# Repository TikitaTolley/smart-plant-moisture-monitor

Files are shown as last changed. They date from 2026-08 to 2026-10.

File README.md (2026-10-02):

# Smart Plant Moisture Monitor

> An ESP32 smart plant monitor with a capacitive soil sensor, a 3D-printed RGB status lamp and an installable pixel-art PWA.

The finished build uses soldered electronics inside a 3D-printed controller enclosure. After a short overheated the original board, I rebuilt the circuit on a new board, tested it and fitted it into the case.

[][yt]
[][tt]
[][ig]

<p>
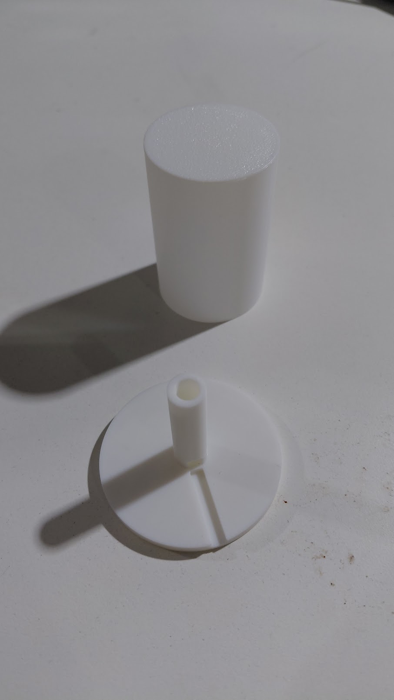
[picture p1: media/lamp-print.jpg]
Printed lamp shade and base
  
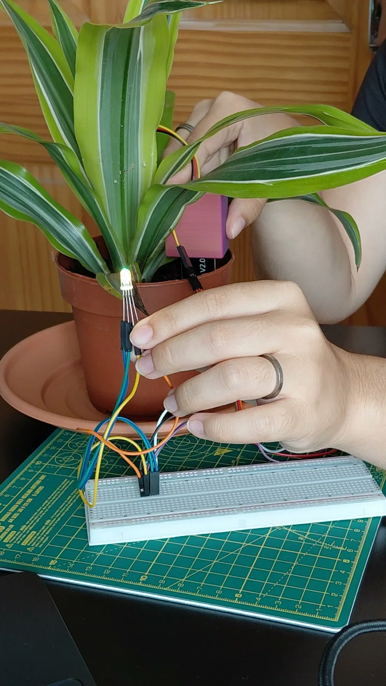
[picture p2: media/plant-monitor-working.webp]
Working ESP32 plant monitor with a soil sensor and green status LED beside the plant
  
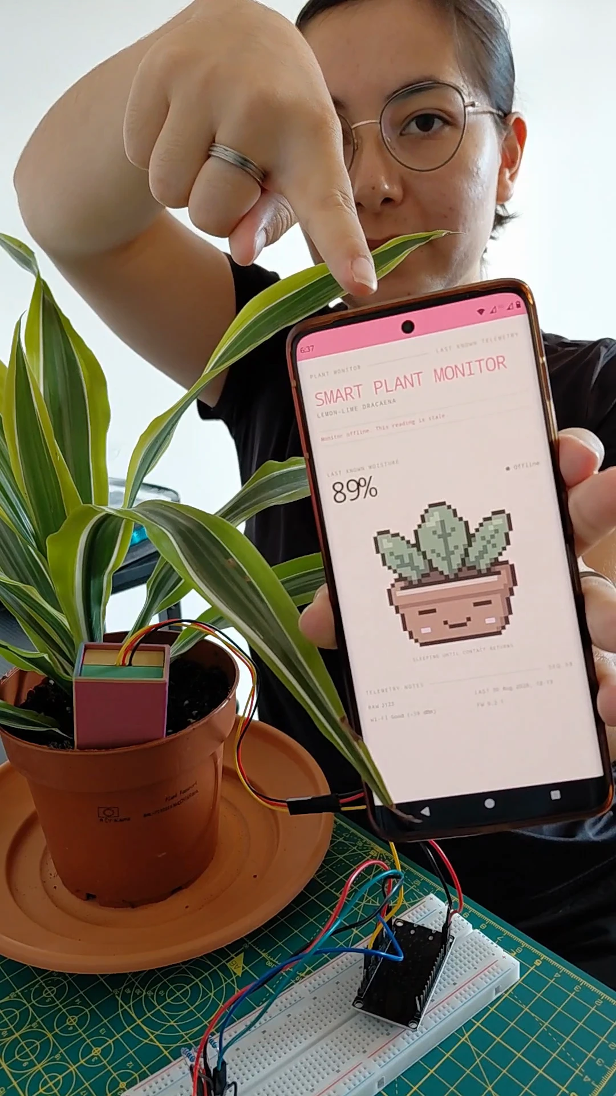
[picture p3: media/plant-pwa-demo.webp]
Tikita holding the Smart Plant Monitor PWA beside the plant, soil sensor, and ESP32 circuit
  
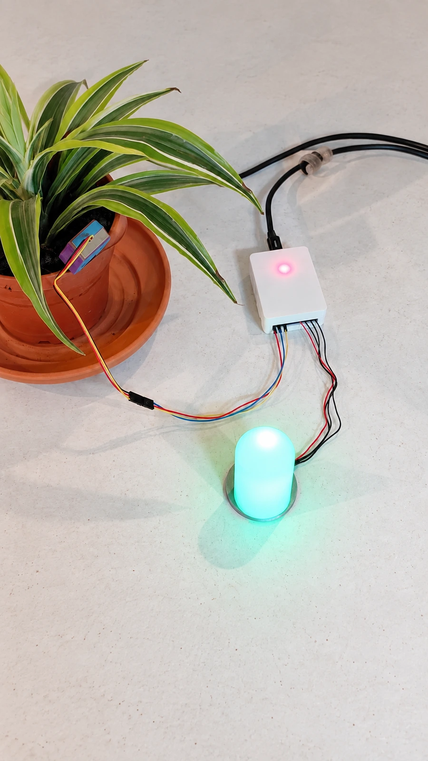
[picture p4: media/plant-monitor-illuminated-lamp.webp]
Finished Smart Plant Moisture Monitor with the plant sensor, controller enclosure and illuminated RGB status lamp
  
</p>

**[Open the live Smart Plant Monitor][live-pwa]**

## What it does

A capacitive sensor reads the soil moisture around the plant. The ESP32 shows the current status on the RGB lamp and sends the reading to a Cloudflare-backed PWA.

The monitor has three live moisture states:

| Moisture state | Lamp | PWA character |
| --- | --- | --- |
| Moist | Green | Happy |
| Getting dry | Yellow | Worried |
| Dry | Red | Sad |

The sleeping character means the monitor is offline.

## Simulated circuit

| Simulator | Link | Notes |
| --- | --- | --- |
| Wokwi | [Open the simulation][wokwi] | ESP32, moisture input, and RGB output logic |

## Bill of materials

| Qty | Component | Part | Unit cost | Notes |
| --- | --- | --- | --- | --- |
| 1 | Starter kit | ESP32 Basic Starter Kit | £12.89 bundle | Shared purchase; included parts below are not charged again |
| 1 | Microcontroller | ESP32 development board | Included in kit | 3.3 V logic |
| 1 | Perfboard | 50 x 70 mm | From £8.99 assorted pack | Soldered circuit |
| 2 | Female header strips | Cut to 15 contacts | £0.10 per strip | ESP32 sockets |
| 3 | Terminal blocks | One 3-way, two 2-way | Pack cost not allocated | Sensor and lamp connections |
| 1 | USB cable | Data cable | Owned | |
| 1 | RGB LED | 5 mm, common cathode | Included in kit | One of two supplied in the kit |
| 3 | Resistor | 220 Ω from assorted pack | Included in kit | Three of 30 supplied in the kit |
| As needed | Wire | Jumpers and hook-up wire | Shared supplies | |
| 1 | Soil moisture sensor | Capacitive v1.2 | £0.48 | 3.3 to 5.5 V input, 0 to 3.0 V output, PH2.0-3P, 98 x 23 mm |
| 38.02 g | Lamp and sensor-case parts | PLA Basic | £1.33 | 26.16 g colourful white + 11.86 g white |
| 60.32 g | Controller-enclosure prints | White PLA | £2.11 | Recorded as 44.14 g + 16.18 g |
| 1 | Mains USB plug | 5 V USB | Owned | |
| 1 | Plant | Potted plant | £4.99 | |

## Wiring

| Component | Pin | ESP32 connection | Notes |
| --- | --- | --- | --- |
| Soil moisture sensor | VCC | 3V3 | Shared 3.3 V rail |
| Soil moisture sensor | GND | GND | Common ground |
| Soil moisture sensor | AOUT | GPIO 34 | ADC1 pin |
| RGB LED | Common cathode | GND | |
| RGB LED | Red anode | GPIO 25 through 220 Ω | PWM |
| RGB LED | Green anode | GPIO 26 through 220 Ω | PWM |
| RGB LED | Blue anode | GPIO 27 through 220 Ω | PWM |

## Firmware

The Arduino sketch is [`main/main.ino`](main/main.ino). It uses the ESP32 Arduino core.

1. Copy `main/secrets.example.h` to `main/secrets.h`.
2. Add the Wi-Fi details, API URL, and device key.
3. Open `main/main.ino` in Arduino IDE.
4. Select the matching ESP32 board and port, then upload the sketch.
5. Open Serial Monitor at 115200 baud.

### Soil calibration

Current references: `dryRaw = 2559`, `wetRaw = 1741`. For your plant, average the Serial Monitor raw readings in dry soil and after watering has settled, then update those two constants. The percentage is relative to your references.

## Web app

The installable React and Vite PWA receives readings through a Cloudflare Worker and stores them in D1.

[Open the live Smart Plant Monitor][live-pwa]

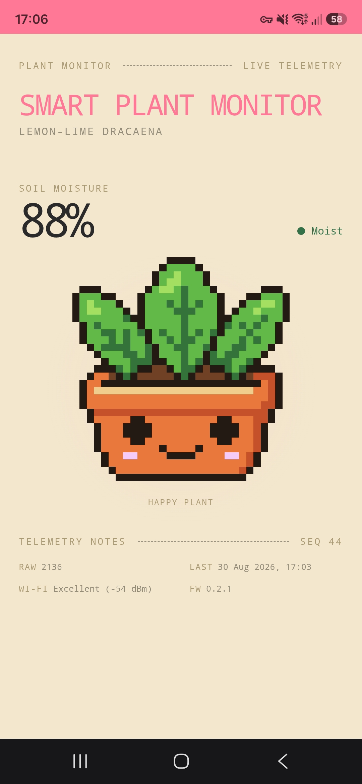
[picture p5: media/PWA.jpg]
Smart Plant Monitor PWA showing a pixel-art plant character


```sh
cd app
bun install
bun run dev
```

See [app setup](app/README.md) for the device key, database and deployment steps.

## Printed sensor case

The sensor case is based on [danielkrah's Capacitive Soil Moisture Sensor v1.2 Case][printables-vendor]. The four parts used here are in `print/stl/`:

| File | Part |
| --- | --- |
| [v4-outer-box.stl](print/stl/v4-outer-box.stl) | Protective sleeve |
| [v4-upper-case.stl](print/stl/v4-upper-case.stl) | Upper case half |
| [v4-bottom-case.stl](print/stl/v4-bottom-case.stl) | Lower case half |
| [v4-sensor-dummy.stl](print/stl/v4-sensor-dummy.stl) | Fit-test sensor dummy |

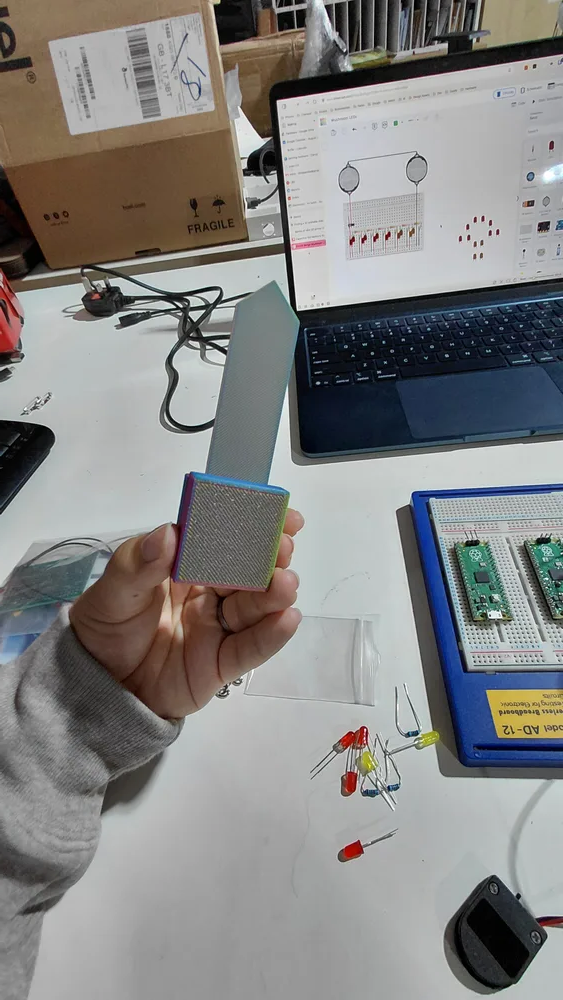
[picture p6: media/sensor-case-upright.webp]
Printed sensor case


## RGB lamp head

The custom shade softens the LED and the base routes the four LED wires into the stake. The tested files target a **Bambu Lab P1S with a 0.4 mm nozzle** and use 0.2 mm layers.

| File | Contents |
| --- | --- |
| [print/3mf/lamp-shade-project.3mf](print/3mf/lamp-shade-project.3mf) | Combined Bambu Studio project with verified shade and v3 base |
| [print/3mf/lamp-shade-final.3mf](print/3mf/lamp-shade-final.3mf) | Verified shade, 0% infill |
| [print/3mf/lamp-shade-base-v3-final.3mf](print/3mf/lamp-shade-base-v3-final.3mf) | Verified base, 15% infill |
| [print/3mf/print-profile.3mf](print/3mf/print-profile.3mf) | Two configured plates: shade at 0% infill and v3 base at 15% infill |

The lamp files are also published as [RGB LED Lamp Shade on MakerWorld][makerworld-lamp].

## Controller enclosure

The USB-powered ESP32 and soldered perfboard sit inside a case with a removable carrier and lid.

| CAD download | Part |
| --- | --- |
| [Body](cad/controller/controller-body.step) | Perfboard supports and wire clearance |
| [Carrier](cad/controller/controller-carrier.step) | Removable ESP32 support |
| [Lid](cad/controller/controller-lid.step) | Lift-off cover |

These STEP files need orientation and slicing for your printer.
The [Onshape source document][onshape-controller] contains the design history and named revisions.
The controller enclosure is available through GitHub rather than model-sharing platforms.

<p>
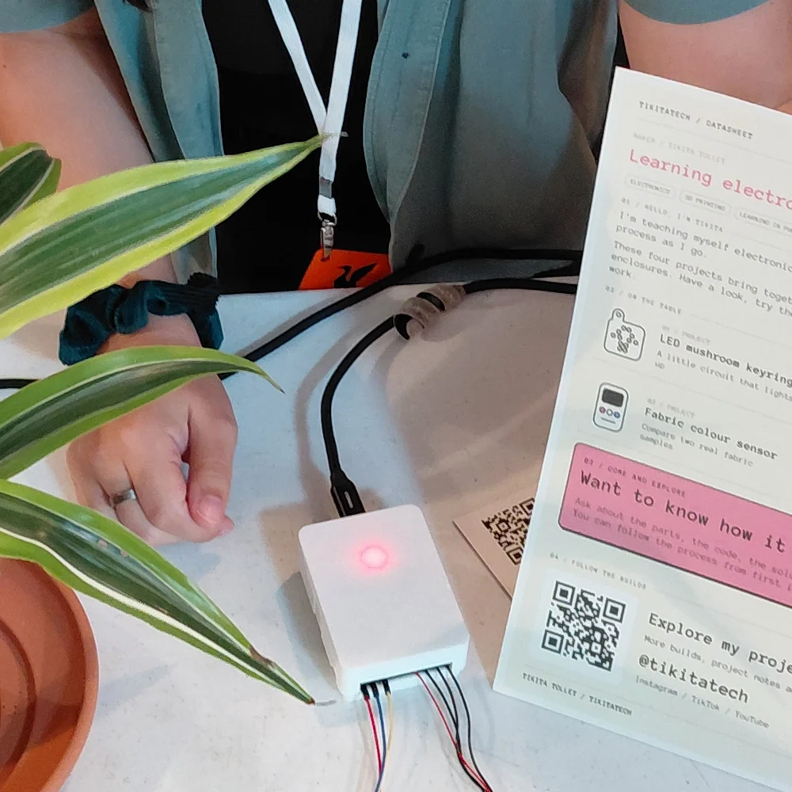
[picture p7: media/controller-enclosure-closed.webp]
Finished Smart Plant Moisture Monitor controller enclosure
  
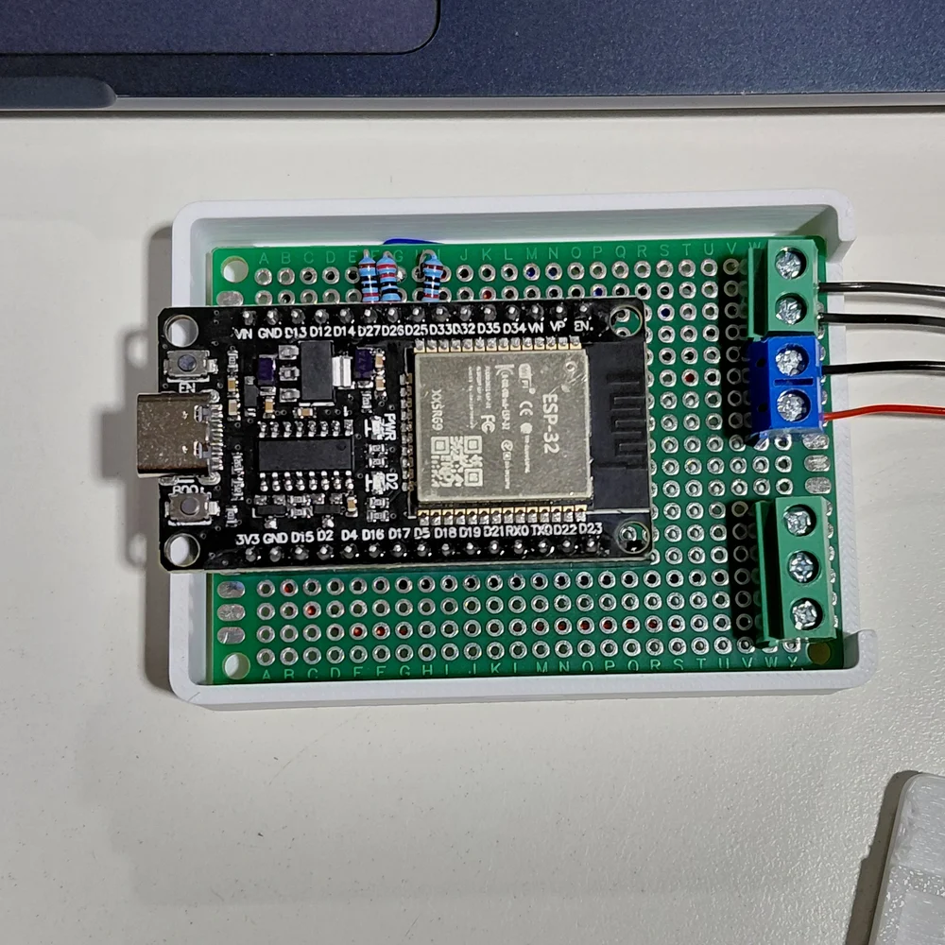
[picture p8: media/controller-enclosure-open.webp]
Open Smart Plant Moisture Monitor controller enclosure showing the ESP32, perfboard and terminal blocks
  
</p>

## Build videos

- [Prototype to finished build](https://www.youtube.com/shorts/TpMN1hflvZs)
- [Board rebuild](https://www.youtube.com/shorts/PaTFUJps23Y)

## This project elsewhere

| Where | Link | What is there |
| --- | --- | --- |
| Live PWA | [Open the Smart Plant Monitor][live-pwa] | Latest reading and pixel-art moisture state |
| Portfolio | [Read the project page][portfolio] | Full build overview |
| MakerWorld | [RGB LED Lamp Shade][makerworld-lamp] | Lamp files and print details |
| Onshape | [Open the controller enclosure source][onshape-controller] | Controller design history and named revisions |
| Printables | [Original sensor case][printables-vendor] | Source enclosure design by danielkrah |
| YouTube Shorts | [Watch Part 1][part1-youtube] · [Watch Part 2][part2-youtube] | RGB lamp build and wireless PWA build |
| TikTok | [Watch Part 1][part1-tiktok] · [Watch Part 2][part2-tiktok] | RGB lamp build and wireless PWA build |
| Instagram | [Watch Part 1][part1-instagram] · [Watch Part 2][part2-instagram] | RGB lamp build and wireless PWA build |

## Licences

- Software and firmware: [MIT](LICENSE)
- Original lamp shade, base, controller CAD, build documentation and released project photographs: [CC BY-NC-SA 4.0](LICENSE)
- Sensor-case meshes by danielkrah: [CC BY-SA 4.0](LICENSE)

---

All projects at [github.com/TikitaTolley][gh].

[yt]: https://youtube.com/@tikitatech
[tt]: https://tiktok.com/@tikitatech
[ig]: https://instagram.com/tikitatech
[gh]: https://github.com/TikitaTolley
[portfolio]: https://tikitatech.xyz/projects/smart-plant-moisture-monitor/
[wokwi]: https://wokwi.com/projects/471268493966479361
[makerworld-lamp]: https://makerworld.com/en/models/3173248-rgb-led-lamp-shade
[onshape-controller]: https://cad.onshape.com/documents/6bfe477083b9e3ae1efd160d/w/e42f85ce378bae2f44ccfe51/e/629ef28bf58cca82b9749cb0
[printables-vendor]: https://www.printables.com/model/277601-capacitive-soil-moisture-sensor-v12-case-waterproo
[part1-youtube]: https://youtube.com/shorts/DsD2whw1M_8
[part1-tiktok]: https://www.tiktok.com/@tikitatech/video/7675019173306633494
[part1-instagram]: https://www.instagram.com/reel/DcJU_JGqnMz/
[part2-youtube]: https://youtube.com/shorts/lq9Cll0Gkk8
[part2-tiktok]: https://www.tiktok.com/@tikitatech/video/7680212442886032673
[part2-instagram]: https://www.instagram.com/reel/DctX8B5qHho/
[live-pwa]: https://smart-plant-monitor.daeda-technologies.workers.dev

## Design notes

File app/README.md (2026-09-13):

# Smart Plant Monitor app

An installable React PWA, Cloudflare Worker and D1 database. [Open the live monitor](https://smart-plant-monitor.daeda-technologies.workers.dev/).

## Local setup

From the repository root, with Bun installed:

```sh
cd app
bun install
cp .dev.vars.example .dev.vars
bunx wrangler d1 migrations apply smart-plant-monitor --local
bun run dev
```

Set `DEVICE_KEY` in `.dev.vars` to your own random secret. In another terminal, from `app/`, run `bun run simulate:local` to send synthetic readings.

## Deploy your own

1. Run `bunx wrangler login`, then `bunx wrangler d1 create smart-plant-monitor` in your Cloudflare account.
2. Set your Worker name and returned database ID in [wrangler.jsonc](wrangler.jsonc). Keep the binding `DB`.
3. Apply the migration, set your device key and deploy:

```sh
bunx wrangler d1 migrations apply smart-plant-monitor --remote
bunx wrangler secret put DEVICE_KEY
bun run deploy
```

In `main/secrets.h`, set the same device key, your Wi-Fi details and `API_URL` to `https://YOUR-WORKER.workers.dev/api/v1/readings/`.

[Cloudflare database setup](https://developers.cloudflare.com/d1/get-started/) · [Worker secrets](https://developers.cloudflare.com/workers/configuration/secrets/)

## Checks

```sh
bun run build
bun run lint
```

The firmware calculates the moisture state; the app displays it. A sleeping character means the device is offline.

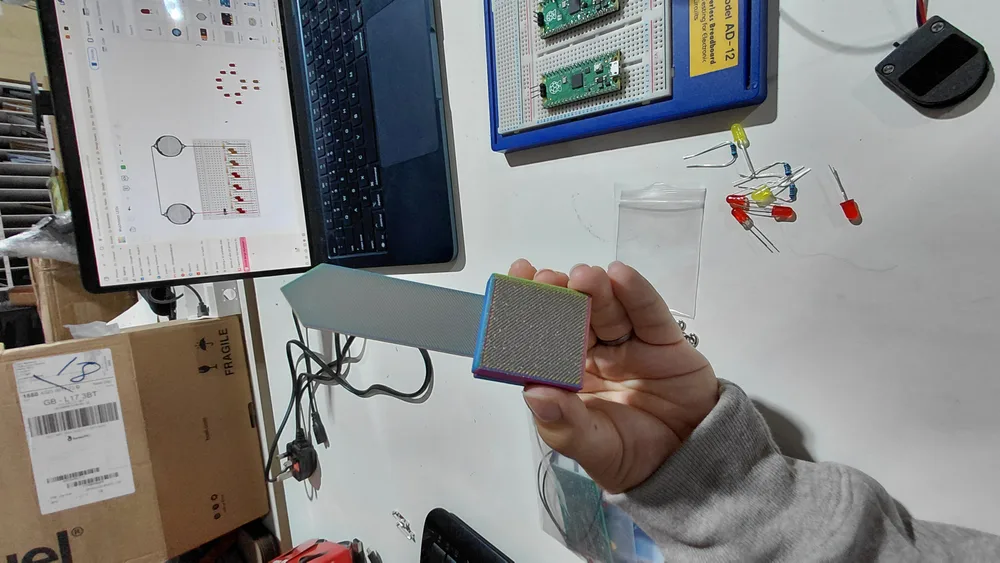
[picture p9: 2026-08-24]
media/sensor-case.webp

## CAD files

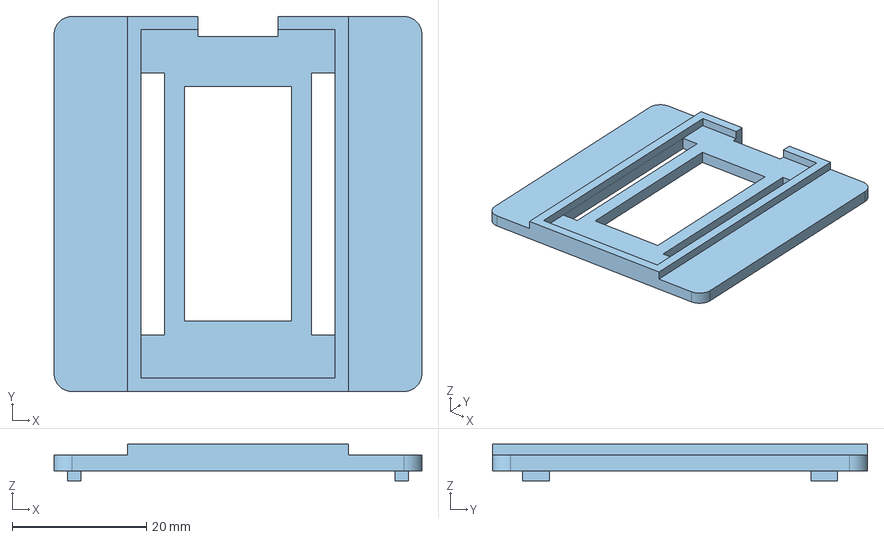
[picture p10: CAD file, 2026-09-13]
cad/controller/controller-carrier.step
54.9 x 56.0 x 5.50 mm

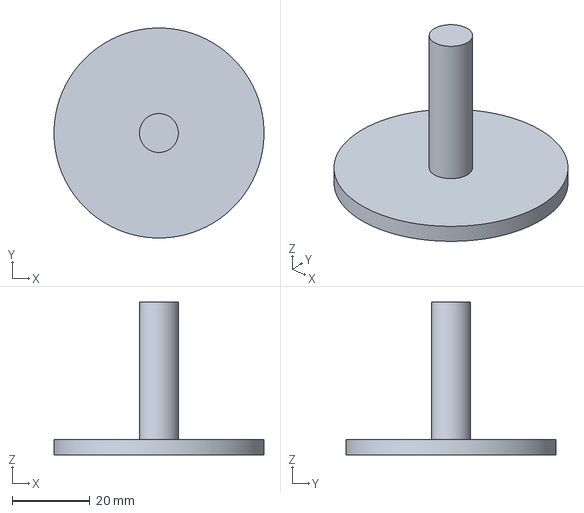
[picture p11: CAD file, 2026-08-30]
print/3mf/early-iterations/lamp-shade-base-v2-final.3mf
54.0 x 54.0 x 39.3 mm

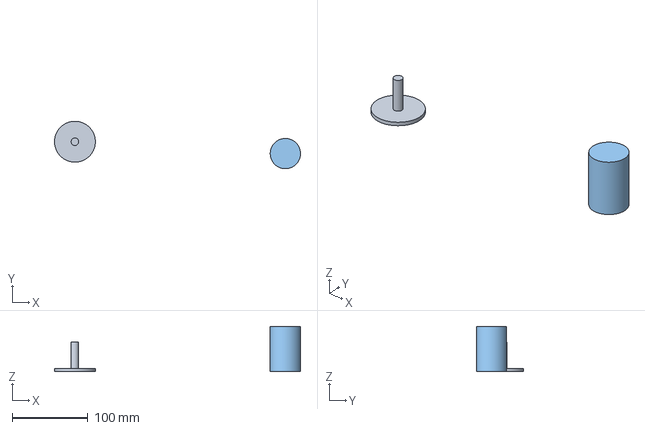
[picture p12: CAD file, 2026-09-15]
print/3mf/print-profile.3mf
324.9 x 62.7 x 60.0 mm

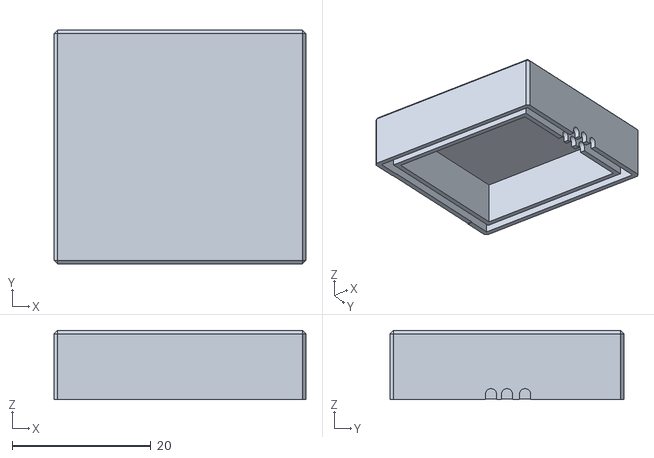
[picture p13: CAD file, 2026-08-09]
print/stl/v4-upper-case.stl
36.3 x 33.7 x 10.0

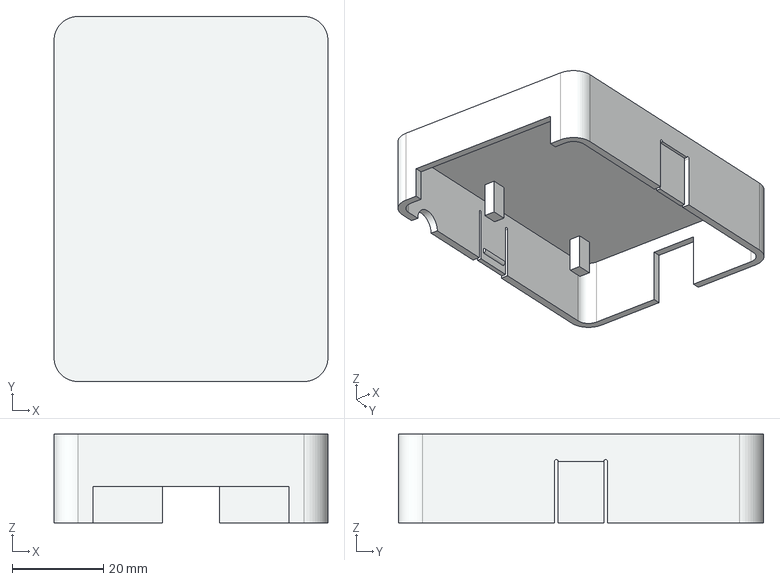
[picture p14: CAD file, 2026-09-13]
cad/controller/controller-lid.step
60.1 x 80.1 x 19.5 mm

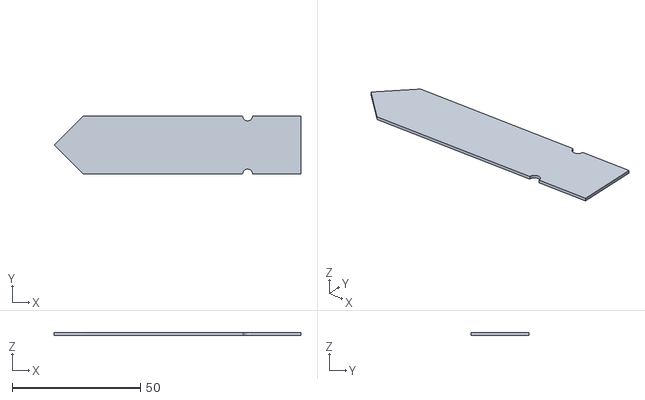
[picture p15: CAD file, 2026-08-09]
print/stl/v4-sensor-dummy.stl
96.2 x 22.6 x 1.00

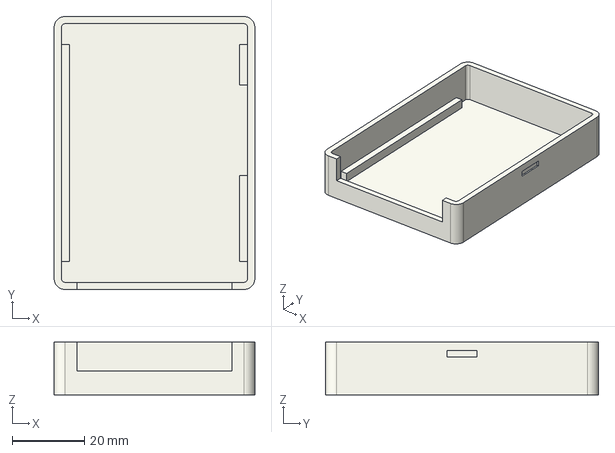
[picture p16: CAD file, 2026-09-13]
cad/controller/controller-body.step
55.5 x 75.5 x 14.6 mm

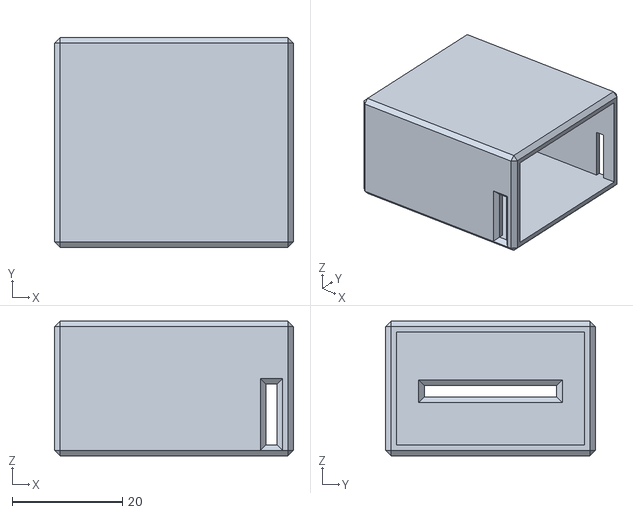
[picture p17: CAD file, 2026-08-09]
print/stl/v4-outer-box.stl
43.3 x 38.1 x 24.4

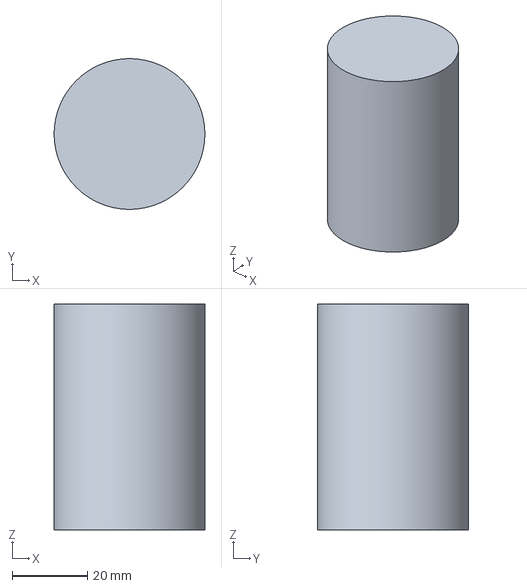
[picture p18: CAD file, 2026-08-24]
print/3mf/lamp-shade-final.3mf
40.0 x 40.0 x 60.0 mm

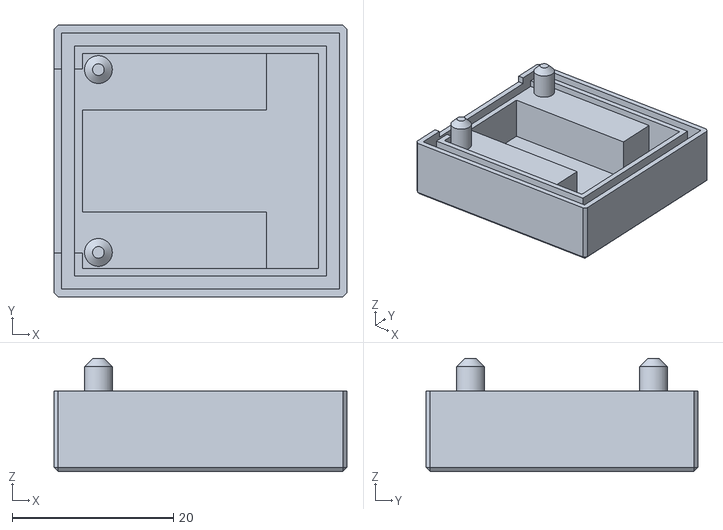
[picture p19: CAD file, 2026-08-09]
print/stl/v4-bottom-case.stl
36.3 x 33.7 x 14.0

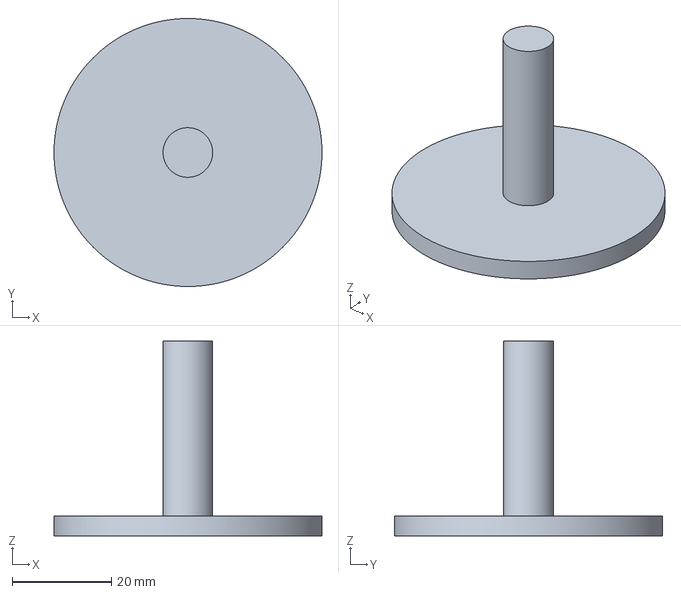
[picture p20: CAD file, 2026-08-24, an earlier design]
print/3mf/early-iterations/lamp-shade-base-final.3mf
54.0 x 54.0 x 39.3 mm

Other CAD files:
print/3mf/lamp-shade-project.3mf
print/3mf/lamp-shade-base-v3-final.3mf

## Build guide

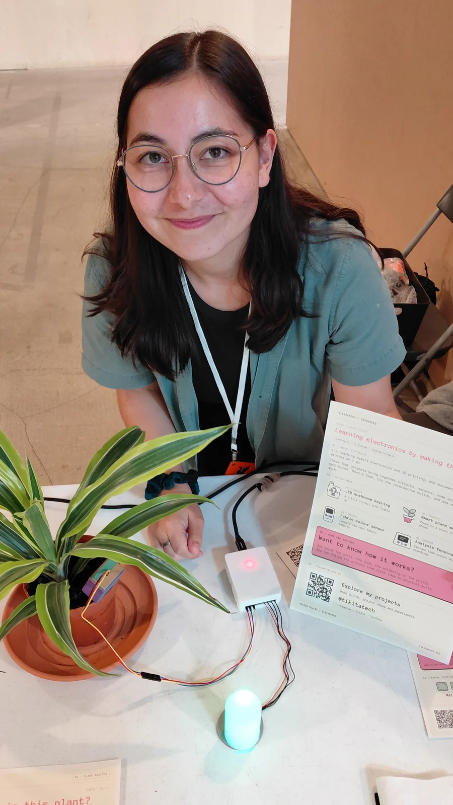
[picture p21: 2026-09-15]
media/plant-monitor-makefest.webp

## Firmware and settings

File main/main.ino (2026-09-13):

#include <HTTPClient.h>
#include <NetworkClientSecure.h>
#include <Preferences.h>
#include <WiFi.h>
#include <time.h>
#include "certificates.h"
#include "secrets.h"

constexpr int moisturePin = 34;
constexpr int redPin = 25;
constexpr int greenPin = 26;
constexpr int bluePin = 27;

constexpr int dryRaw = 2559; // measured dry-soil reference
constexpr int wetRaw = 1741; // settled after light watering; relative reference
constexpr char deviceId[] = "lemon-lime-dracaena-01";
constexpr char firmwareVersion[] = "0.3.0";
constexpr unsigned long uploadIntervalMs = 300000;
constexpr time_t minimumValidTime = 1700000000;

unsigned long sequence = 1;
unsigned long lastUploadAttemptAt = 0;
unsigned long lastSerialReadingAt = 0;
bool firstUploadAttempted = false;
Preferences preferences;
bool preferencesReady = false;
char pendingPayload[256];
bool hasPendingReading = false;

void loadSequence() {
  preferencesReady = preferences.begin("plant-monitor", false);

  if (!preferencesReady) {
    Serial.println("Failed to open sequence storage");
    return;
  }

  sequence = preferences.getULong("next-seq", 1);
  Serial.print("Next reading sequence: ");
  Serial.println(sequence);
}

bool advanceSequence() {
  if (!preferencesReady) {
    Serial.println("Sequence storage is unavailable");
    return false;
  }

  if (sequence == UINT32_MAX) {
    Serial.println("Sequence has reached its maximum value");
    return false;
  }

  const unsigned long nextSequence = sequence + 1;

  if (preferences.putULong("next-seq", nextSequence) == 0) {
    Serial.println("Failed to save sequence");
    return false;
  }

  sequence = nextSequence;
  return true;
}

float moisturePercent(int raw) {
  const float percent =
    100.0f * (dryRaw - raw) / (dryRaw - wetRaw);
  return constrain(percent, 0.0f, 100.0f);
}

int readAverageMoisture() {
  constexpr int sampleCount = 10;
  int total = 0;

  for (int sample = 0; sample < sampleCount; sample++) {
    total += analogRead(moisturePin);
    delay(10);
  }

  return total / sampleCount;
}

const char* moistureStatus(int percent) {
  if (percent <= 25) {
    return "dry";
  }

  if (percent <= 45) {
    return "getting-dry";
  }

  return "moist";
}

bool formatReadingJson(
  char* buffer,
  size_t bufferSize,
  int raw,
  int percent
) {
  const char* status = moistureStatus(percent);
  const int rssi = WiFi.RSSI();

  const int length = snprintf(
    buffer,
    bufferSize,
    "{\"deviceId\":\"%s\","
    "\"sequence\":%lu,"
    "\"raw\":%d,"
    "\"moisturePercent\":%d,"
    "\"status\":\"%s\","
    "\"rssi\":%d,"
    "\"firmwareVersion\":\"%s\"}",
    deviceId,
    sequence,
    raw,
    percent,
    status,
    rssi,
    firmwareVersion
  );

  return length >= 0 && static_cast<size_t>(length) < bufferSize;
}

bool clockIsReady() {
  return time(nullptr) >= minimumValidTime;
}

bool sendReading(const char* payload) {
  if (WiFi.status() != WL_CONNECTED) {
    Serial.println("Upload deferred: Wi-Fi is disconnected");
    return false;
  }

  if (!clockIsReady()) {
    Serial.println("Upload deferred: waiting for clock sync");
    return false;
  }

  NetworkClientSecure client;
  client.setCACert(gtsRootR4);

  HTTPClient http;

  if (!http.begin(client, API_URL)) {
    Serial.println("Failed to start HTTPS request");
    return false;
  }

  const String authorization = String("Bearer ") + DEVICE_KEY;
  http.addHeader("Authorization", authorization);
  http.addHeader("Content-Type", "application/json");

  Serial.print("Uploading sequence ");
  Serial.println(sequence);

  const int responseCode = http.POST(String(payload));
  const bool accepted = responseCode == 200 || responseCode == 201;

  if (responseCode > 0) {
    Serial.print("Worker response: ");
    Serial.println(responseCode);
  } else {
    Serial.print("HTTPS request failed: ");
    Serial.println(http.errorToString(responseCode));
  }

  http.end();
  return accepted;
}

void setColour(int red, int green, int blue) {
  analogWrite(redPin, red);
  analogWrite(greenPin, green);
  analogWrite(bluePin, blue);
}

constexpr unsigned long wifiRetryIntervalMs = 30000;

unsigned long lastWifiAttemptAt = 0;
bool wifiWasConnected = false;

void startWifi() {
  Serial.print("Connecting to ");
  Serial.println(WIFI_SSID);

  WiFi.mode(WIFI_STA);
  WiFi.begin(WIFI_SSID, WIFI_PASSWORD);

  lastWifiAttemptAt = millis();
}

void maintainWifi() {
  const bool wifiIsConnected = WiFi.status() == WL_CONNECTED;

  if (wifiIsConnected) {
    if (!wifiWasConnected) {
      Serial.println("Wi-Fi connected");
      Serial.print("IP address: ");
      Serial.println(WiFi.localIP());
      configTime(0, 0, "pool.ntp.org", "time.nist.gov");
      Serial.println("Clock sync requested");
    }

    wifiWasConnected = true;
    return;
  }

  if (wifiWasConnected) {
    Serial.println("Wi-Fi disconnected");
  }

  wifiWasConnected = false;

  const unsigned long now = millis();

  if (now - lastWifiAttemptAt < wifiRetryIntervalMs) {
    return;
  }

  lastWifiAttemptAt = now;

  Serial.println("Retrying Wi-Fi connection...");
  WiFi.reconnect();
}

void setup() {
  Serial.begin(115200);

  loadSequence();
  analogReadResolution(12);

  pinMode(redPin, OUTPUT);
  pinMode(greenPin, OUTPUT);
  pinMode(bluePin, OUTPUT);

  Serial.println("Smart Plant Moisture Monitor ready");
  startWifi();
}

void loop() {
  maintainWifi();
  const int moisture = readAverageMoisture();

  const int percent = moisturePercent(moisture);

  const unsigned long now = millis();

  if (percent <= 25) {
    setColour(255, 0, 0);     // dry: red
  } else if (percent <= 45) {
    setColour(255, 100, 0);   // getting dry: yellow
  } else {
    setColour(0, 255, 0);     // moist: green
  }

  if (now - lastSerialReadingAt >= 1000) {
    lastSerialReadingAt = now;
    Serial.printf("raw=%d relativeMoisture=%d%% status=%s wifi=%s\n",
      moisture, percent, moistureStatus(percent),
      WiFi.status() == WL_CONNECTED ? "connected" : "disconnected");
  }

  // Allow settling before the first online reading, then retain five-minute uploads.
  const bool firstUploadReady = !firstUploadAttempted && now >= 30000 &&
    WiFi.status() == WL_CONNECTED && clockIsReady();
  const bool nextUploadReady = firstUploadAttempted &&
    now - lastUploadAttemptAt >= uploadIntervalMs;

  if (firstUploadReady || nextUploadReady) {
    firstUploadAttempted = true;
    lastUploadAttemptAt = now;

    if (!hasPendingReading) {
      hasPendingReading = formatReadingJson(
        pendingPayload,
        sizeof(pendingPayload),
        moisture,
        percent
      );

      if (hasPendingReading) {
        Serial.print("Reading queued: ");
        Serial.println(pendingPayload);
      } else {
        Serial.println("Reading JSON was too large");
      }
    }

    if (hasPendingReading && sendReading(pendingPayload)) {
      if (advanceSequence()) {
        hasPendingReading = false;
        pendingPayload[0] = '\0';
        Serial.println("Reading accepted and sequence advanced");
      }
    }
  }

  delay(50);
}

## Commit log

2026-08-09 add capacitive sensor 3d print and project parts
    [v4-bottom-case.stl, v4-outer-box.stl, v4-sensor-dummy.stl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]
2026-08-24 moisture reading, lamp shade files, update license
    [lamp-shade-base-final.3mf, lamp-shade-final.3mf, lamp-shade-project.3mf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]
2026-08-30 pixel chars, new lamp base print design, pwa app
    [lamp-shade-base-final.3mf, lamp-shade-base-v2-final.3mf, lamp-shade-base-v3-final.3mf]
2026-09-05 Add upright sensor-case photo without cropping
2026-09-05 Add caption-free PWA demonstration frame from day five
2026-09-05 Use selected PWA hook frame at 2.8 seconds
2026-09-06 new average readings with new sensor
2026-09-13 Prepare current build and README for Makefest visitors
    [controller-body.step, controller-carrier.step, controller-lid.step]
2026-09-15 Publish finished plant monitor build
    [lamp-shade-project.3mf, print-profile.3mf]
2026-09-15 Add controller enclosure photos
2026-09-17 Remove unnecessary bill of materials note
2026-10-30 add board layout
